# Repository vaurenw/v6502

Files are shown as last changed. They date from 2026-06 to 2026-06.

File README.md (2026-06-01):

A single-board computer built around a W65C02S 6502 CPU. It uses a Lattice ICE40HX4K FPGA as a custom chipset. The FPGA handles video, audio, keyboard, storage, and address decoding.

---

## Hardware

| Part | What it does |
|---|---|
| W65C02S | Main CPU, socketed |
| ICE40HX4K | FPGA chipset for video, audio, IO |
| 62256 SRAM | 32K RAM, socketed |
| AT28C256 EEPROM | 32K ROM, socketed |
| SN74LVC8T245 × 2 | 5V ↔ 3.3V level shifters for the data bus |
| FT230XS | USB-to-UART bridge for debug |
| MicroSD slot | SPI storage via FPGA |
| VGA connector | 640×480 @ 60Hz, resistor ladder DAC |
| PS/2 connector | Keyboard input, decoded in FPGA |

---

## Memory map

```
0x0000 – 0x7FFF   RAM
0x8000 – 0x8FFF   FPGA registers / VRAM window
0x9000 – 0xBFFF   Expansion
0xC000 – 0xFFFF   ROM
```

---

## Schematic sheets

```
V-6502.kicad_sch       root
├── Power.kicad_sch    USB-C, TVS, LDOs, decoupling
├── CPU.kicad_sch      W65C02S, clock, reset
├── Memory.kicad_sch   SRAM, EEPROM
├── LevelShift.kicad_sch   SN74LVC8T245 data bus bridges
├── FPGA.kicad_sch     ICE40HX4K, config flash, oscillator
├── VGA.kicad_sch      DE-15, RGB resistor ladder
├── PS2.kicad_sch      Mini-DIN-6, ESD, pull-ups
├── SD.kicad_sch       MicroSD slot, SPI
├── Audio.kicad_sch    Buzzer, 3.5mm jack
└── Debug.kicad_sch    FT230XS, UART header, test points
```

---

## Status

**Schematic done.** ERC passes clean.

**PCB layout in progress.** The power section is partially routed.

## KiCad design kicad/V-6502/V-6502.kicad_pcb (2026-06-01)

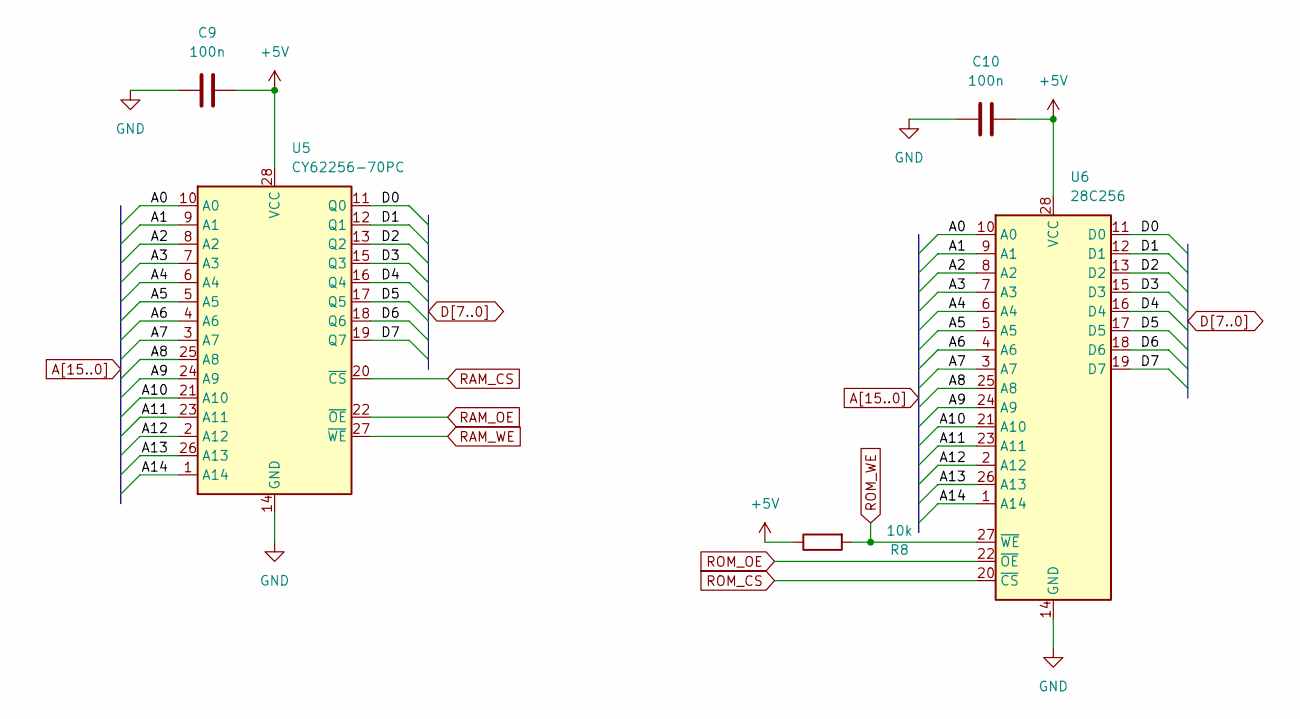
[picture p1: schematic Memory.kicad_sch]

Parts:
C9, C10: 100n; C_0805_2012Metric
R8: 10k; R_0402_1005Metric
U5: CY62256-70PC; DIP-28_W15.24mm_Socket
U6: 28C256; DIP-28_W15.24mm_Socket

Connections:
+5V: C9.2, C10.2, R8.1, U5.28 (VCC), U6.28 (VCC); also elsewhere on the board
A0: U5.10 (A0), U6.10 (A0); also elsewhere on the board
A1: U5.9 (A1), U6.9 (A1); also elsewhere on the board
A2: U5.8 (A2), U6.8 (A2); also elsewhere on the board
A3: U5.7 (A3), U6.7 (A3); also elsewhere on the board
A4: U5.6 (A4), U6.6 (A4); also elsewhere on the board
A5: U5.5 (A5), U6.5 (A5); also elsewhere on the board
A6: U5.4 (A6), U6.4 (A6); also elsewhere on the board
A7: U5.3 (A7), U6.3 (A7); also elsewhere on the board
A8: U5.25 (A8), U6.25 (A8); also elsewhere on the board
A9: U5.24 (A9), U6.24 (A9); also elsewhere on the board
A10: U5.21 (A10), U6.21 (A10); also elsewhere on the board
A11: U5.23 (A11), U6.23 (A11); also elsewhere on the board
A12: U5.2 (A12), U6.2 (A12); also elsewhere on the board
A13: U5.26 (A13), U6.26 (A13); also elsewhere on the board
A14: U5.1 (A14), U6.1 (A14); also elsewhere on the board
D0: U5.11 (Q0), U6.11 (D0); also elsewhere on the board
D1: U5.12 (Q1), U6.12 (D1); also elsewhere on the board
D2: U5.13 (Q2), U6.13 (D2); also elsewhere on the board
D3: U5.15 (Q3), U6.15 (D3); also elsewhere on the board
D4: U5.16 (Q4), U6.16 (D4); also elsewhere on the board
D5: U5.17 (Q5), U6.17 (D5); also elsewhere on the board
D6: U5.18 (Q6), U6.18 (D6); also elsewhere on the board
D7: U5.19 (Q7), U6.19 (D7); also elsewhere on the board
GND: C9.1, C10.1, U5.14 (GND), U6.14 (GND); also elsewhere on the board
RAM_CS: U5.20 (~CS); also elsewhere on the board
RAM_OE: U5.22 (~OE); also elsewhere on the board
RAM_WE: U5.27 (~WE); also elsewhere on the board
ROM_CS: U6.20 (~CS); also elsewhere on the board
ROM_OE: U6.22 (~OE); also elsewhere on the board
ROM_WE: R8.2, U6.27 (~WE); also elsewhere on the board

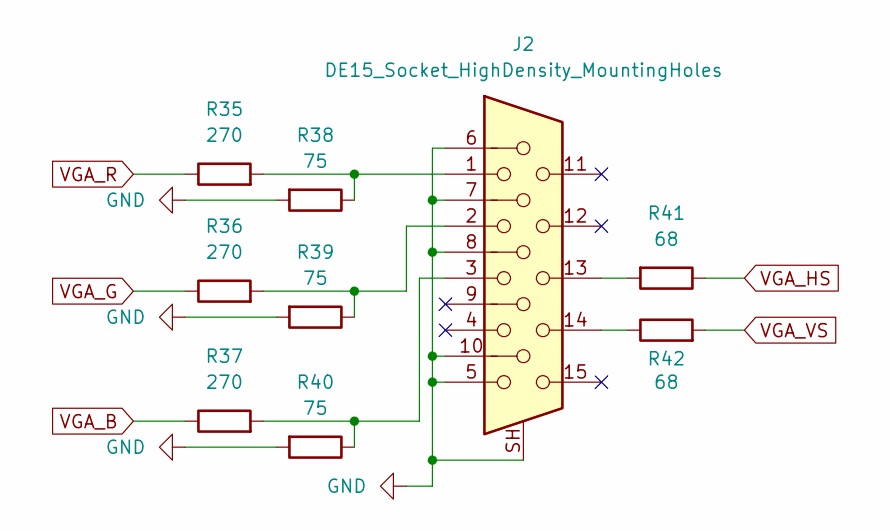
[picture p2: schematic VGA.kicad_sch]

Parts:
J2: DE15_Socket_HighDensity_MountingHoles; DSUB-15-HD_Socket_Vertical_P2.29x1.98mm_MountingHoles
R35, R36, R37: 270; R_0402_1005Metric
R38, R39, R40: 75; R_0402_1005Metric
R41, R42: 68; R_0402_1005Metric

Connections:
GND: J2.5, J2.6, J2.7, J2.8, J2.10, J2.SH, R38.2, R39.2, R40.2; also elsewhere on the board
unnamed: J2.1, R35.2, R38.1
unnamed: J2.2, R36.2, R39.1
unnamed: J2.3, R37.2, R40.1
unnamed: J2.13, R41.2
unnamed: J2.14, R42.1
VGA_B: R37.1; also elsewhere on the board
VGA_G: R36.1; also elsewhere on the board
VGA_HS: R41.1; also elsewhere on the board
VGA_R: R35.1; also elsewhere on the board
VGA_VS: R42.2; also elsewhere on the board

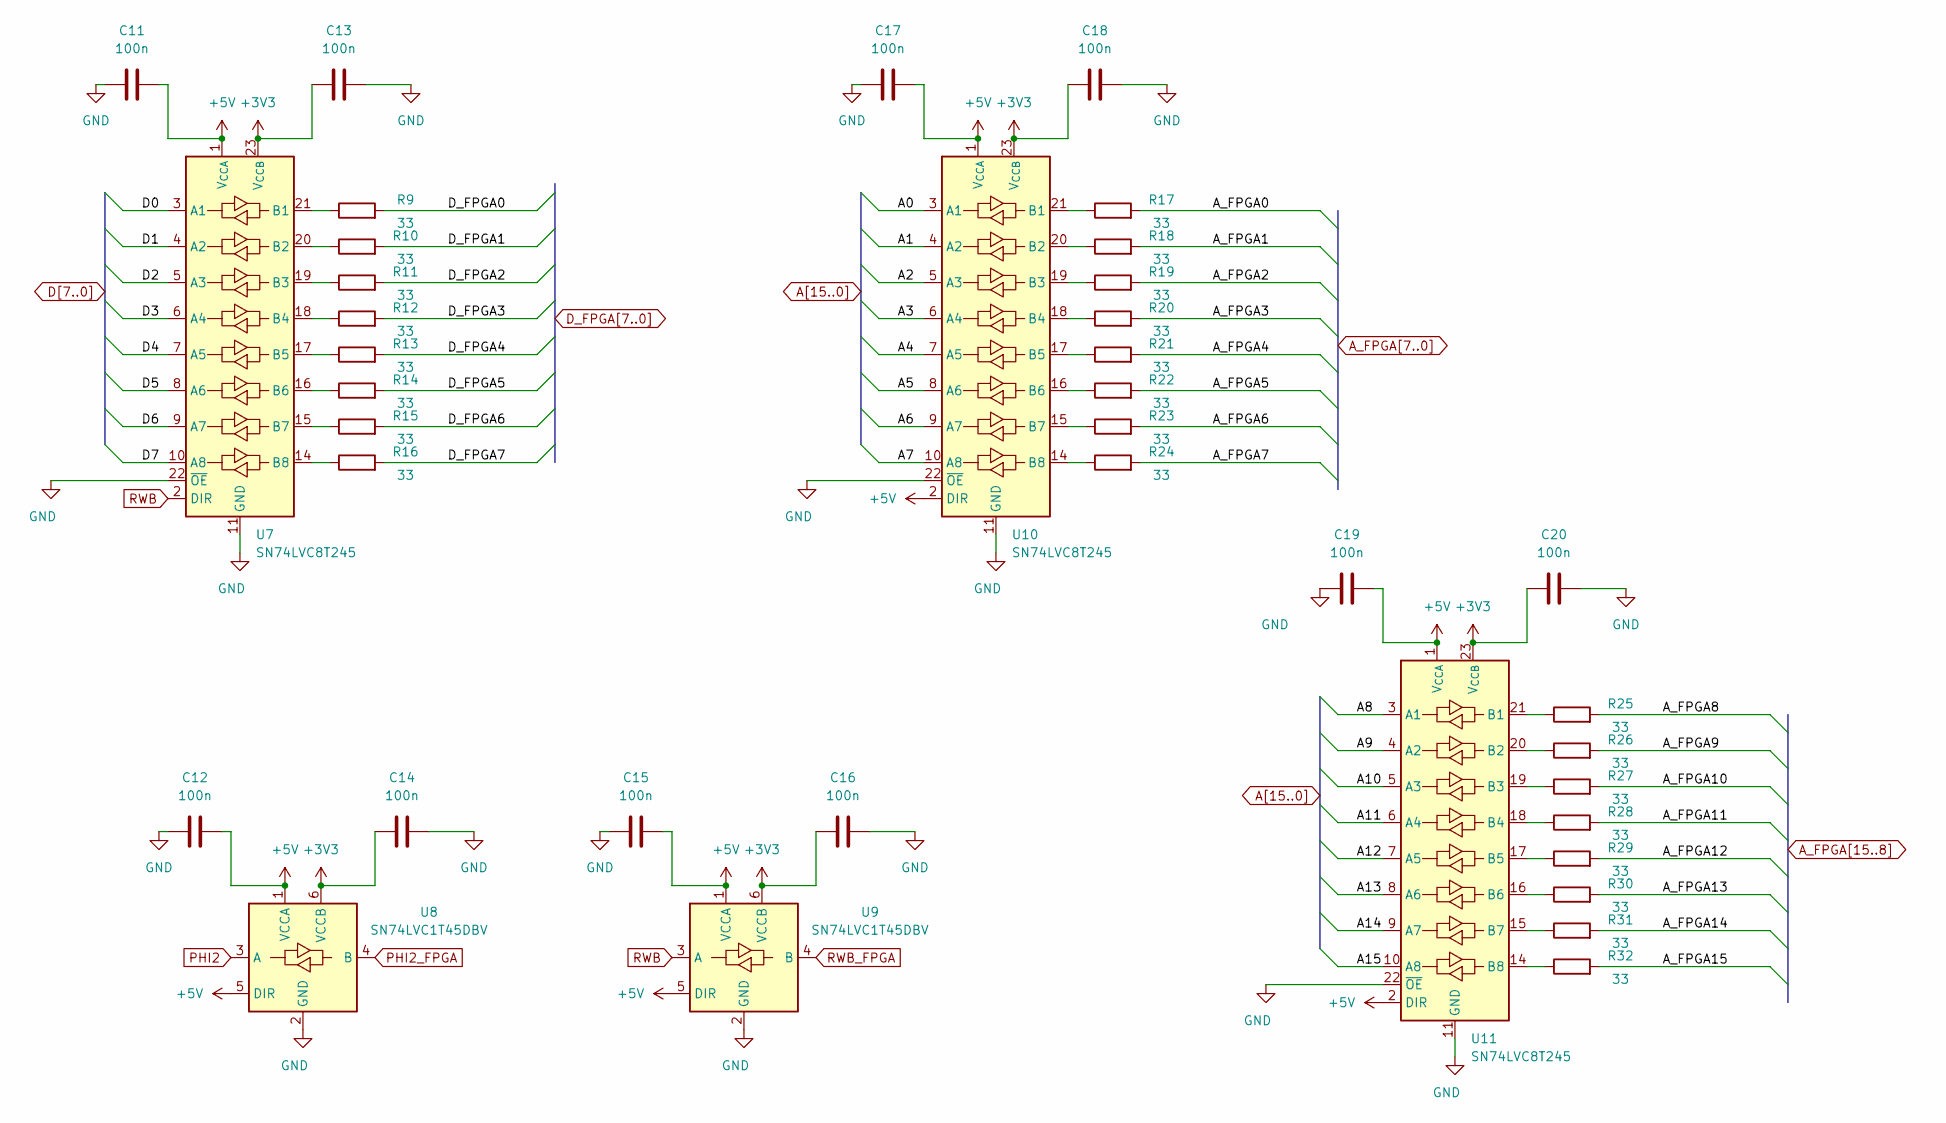
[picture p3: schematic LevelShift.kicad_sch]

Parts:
C11, C12, C13, C14, C15, C16, C17, C18, C19, C20: 100n; C_0805_2012Metric
R9, R10, R11, R12, R13, R14, R15, R16, R17, R18, R19, R20, R21, R22, R23, R24, R25, R26, R27, R28, R29, R30, R31, R32: 33; R_0402_1005Metric
U7, U10, U11: SN74LVC8T245; TSSOP-24_4.4x7.8mm_P0.65mm
U8, U9: SN74LVC1T45DBV; SOT-23-6

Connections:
+3V3: C13.2, C14.2, C16.2, C18.2, C20.2, U7.23 (V_{CCB}), U7.24 (V_{CCB}), U8.6 (VCCB), U9.6 (VCCB), U10.23 (V_{CCB}), U10.24 (V_{CCB}), U11.23 (V_{CCB}), U11.24 (V_{CCB}); also elsewhere on the board
+5V: C11.2, C12.2, C15.2, C17.2, C19.2, U7.1 (V_{CCA}), U8.1 (VCCA), U8.5 (DIR), U9.1 (VCCA), U9.5 (DIR), U10.1 (V_{CCA}), U10.2 (DIR), U11.1 (V_{CCA}), U11.2 (DIR); also elsewhere on the board
A0: U10.3 (A1); also elsewhere on the board
A1: U10.4 (A2); also elsewhere on the board
A2: U10.5 (A3); also elsewhere on the board
A3: U10.6 (A4); also elsewhere on the board
A4: U10.7 (A5); also elsewhere on the board
A5: U10.8 (A6); also elsewhere on the board
A6: U10.9 (A7); also elsewhere on the board
A7: U10.10 (A8); also elsewhere on the board
A8: U11.3 (A1); also elsewhere on the board
A9: U11.4 (A2); also elsewhere on the board
A10: U11.5 (A3); also elsewhere on the board
A11: U11.6 (A4); also elsewhere on the board
A12: U11.7 (A5); also elsewhere on the board
A13: U11.8 (A6); also elsewhere on the board
A14: U11.9 (A7); also elsewhere on the board
A15: U11.10 (A8); also elsewhere on the board
A_FPGA0: R17.2; also elsewhere on the board
A_FPGA1: R18.2; also elsewhere on the board
A_FPGA2: R19.2; also elsewhere on the board
A_FPGA3: R20.2; also elsewhere on the board
A_FPGA4: R21.2; also elsewhere on the board
A_FPGA5: R22.2; also elsewhere on the board
A_FPGA6: R23.2; also elsewhere on the board
A_FPGA7: R24.2; also elsewhere on the board
A_FPGA8: R25.2; also elsewhere on the board
A_FPGA9: R26.2; also elsewhere on the board
A_FPGA10: R27.2; also elsewhere on the board
A_FPGA11: R28.2; also elsewhere on the board
A_FPGA12: R29.2; also elsewhere on the board
A_FPGA13: R30.2; also elsewhere on the board
A_FPGA14: R31.2; also elsewhere on the board
A_FPGA15: R32.2; also elsewhere on the board
D0: U7.3 (A1); also elsewhere on the board
D1: U7.4 (A2); also elsewhere on the board
D2: U7.5 (A3); also elsewhere on the board
D3: U7.6 (A4); also elsewhere on the board
D4: U7.7 (A5); also elsewhere on the board
D5: U7.8 (A6); also elsewhere on the board
D6: U7.9 (A7); also elsewhere on the board
D7: U7.10 (A8); also elsewhere on the board
D_FPGA0: R9.2; also elsewhere on the board
D_FPGA1: R10.2; also elsewhere on the board
D_FPGA2: R11.2; also elsewhere on the board
D_FPGA3: R12.2; also elsewhere on the board
D_FPGA4: R13.2; also elsewhere on the board
D_FPGA5: R14.2; also elsewhere on the board
D_FPGA6: R15.2; also elsewhere on the board
D_FPGA7: R16.2; also elsewhere on the board
GND: C11.1, C12.1, C13.1, C14.1, C15.1, C16.1, C17.1, C18.1, C19.1, C20.1, U7.11 (GND), U7.12 (GND), U7.13 (GND), U7.22 (~OE), U8.2 (GND), U9.2 (GND), U10.11 (GND), U10.12 (GND), U10.13 (GND), U10.22 (~OE), U11.11 (GND), U11.12 (GND), U11.13 (GND), U11.22 (~OE); also elsewhere on the board
unnamed: R9.1, U7.21 (B1)
unnamed: R10.1, U7.20 (B2)
unnamed: R11.1, U7.19 (B3)
unnamed: R12.1, U7.18 (B4)
unnamed: R13.1, U7.17 (B5)
unnamed: R14.1, U7.16 (B6)
unnamed: R15.1, U7.15 (B7)
unnamed: R16.1, U7.14 (B8)
unnamed: R17.1, U10.21 (B1)
unnamed: R18.1, U10.20 (B2)
unnamed: R19.1, U10.19 (B3)
unnamed: R20.1, U10.18 (B4)
unnamed: R21.1, U10.17 (B5)
unnamed: R22.1, U10.16 (B6)
unnamed: R23.1, U10.15 (B7)
unnamed: R24.1, U10.14 (B8)
unnamed: R25.1, U11.21 (B1)
unnamed: R26.1, U11.20 (B2)
unnamed: R27.1, U11.19 (B3)
unnamed: R28.1, U11.18 (B4)
unnamed: R29.1, U11.17 (B5)
unnamed: R30.1, U11.16 (B6)
unnamed: R31.1, U11.15 (B7)
unnamed: R32.1, U11.14 (B8)
PHI2: U8.3 (A); also elsewhere on the board
PHI2_FPGA: U8.4 (B); also elsewhere on the board
RWB: U7.2 (DIR), U9.3 (A); also elsewhere on the board
RWB_FPGA: U9.4 (B); also elsewhere on the board

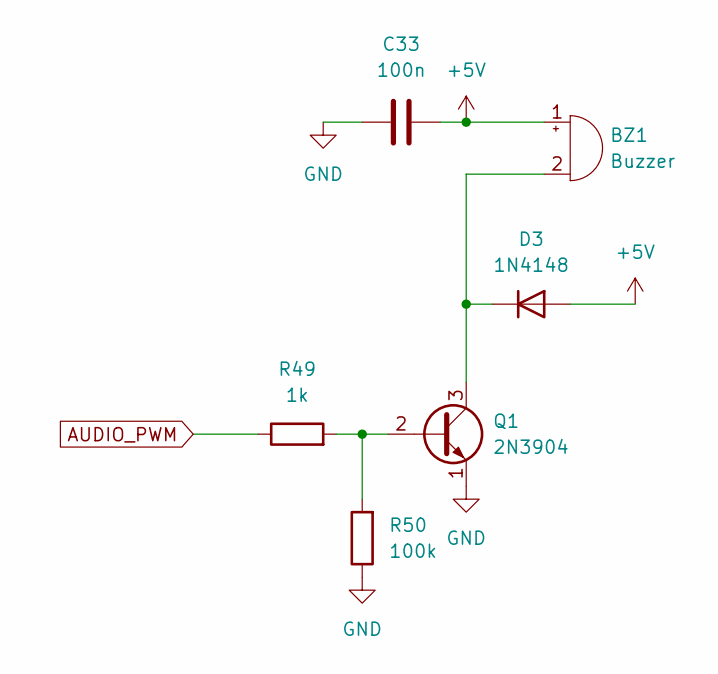
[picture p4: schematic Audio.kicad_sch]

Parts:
BZ1: Buzzer; Buzzer_15x7.5RM7.6
C33: 100n; C_0805_2012Metric
D3: 1N4148; D_DO-35_SOD27_P7.62mm_Horizontal
Q1: 2N3904; TO-92_Inline
R49: 1k; R_0402_1005Metric
R50: 100k; R_0402_1005Metric

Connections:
+5V: BZ1.1 (+), C33.2, D3.2 (A); also elsewhere on the board
AUDIO_PWM: R49.1; also elsewhere on the board
GND: C33.1, Q1.1 (E), R50.1; also elsewhere on the board
unnamed: BZ1.2 (-), D3.1 (K), Q1.3 (C)
unnamed: Q1.2 (B), R49.2, R50.2

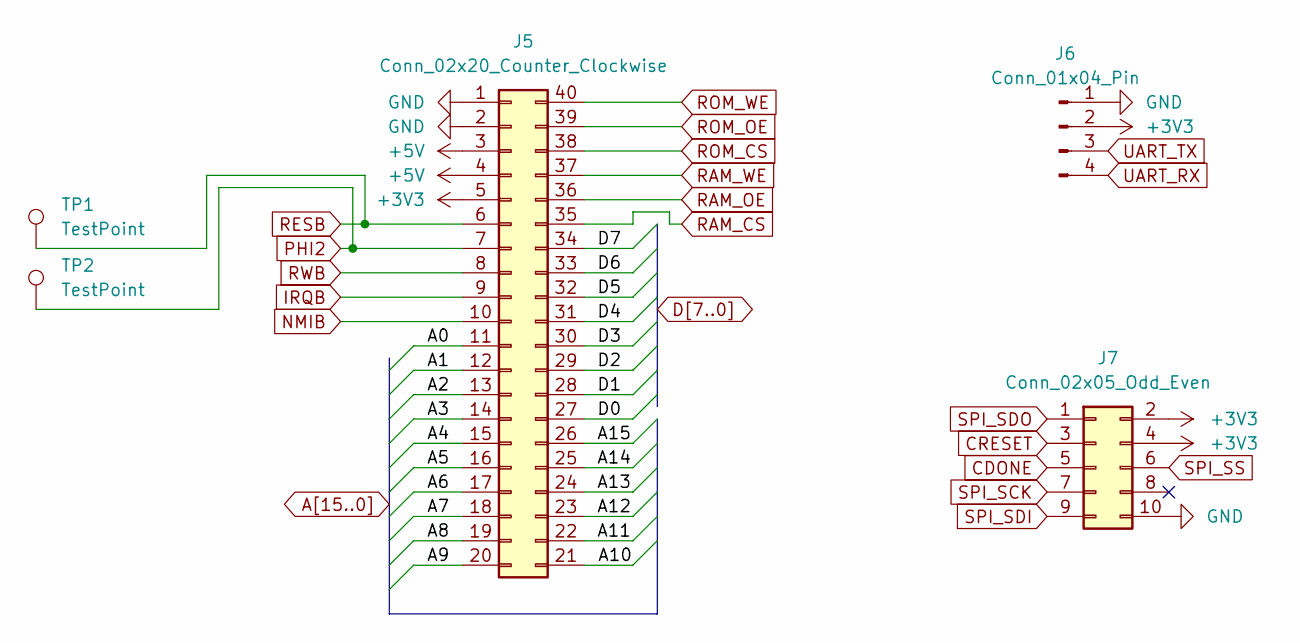
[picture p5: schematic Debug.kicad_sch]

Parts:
J5: Conn_02x20_Counter_Clockwise; PinSocket_2x20_P2.54mm_Vertical
J6: Conn_01x04_Pin; PinHeader_1x04_P2.54mm_Vertical
J7: Conn_02x05_Odd_Even; IDC-Header_2x05_P2.54mm_Vertical
TP1, TP2: TestPoint; TestPoint_Pad_D1.0mm

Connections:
+3V3: J5.5, J6.2, J7.2, J7.4; also elsewhere on the board
+5V: J5.3, J5.4; also elsewhere on the board
A0: J5.11; also elsewhere on the board
A1: J5.12; also elsewhere on the board
A2: J5.13; also elsewhere on the board
A3: J5.14; also elsewhere on the board
A4: J5.15; also elsewhere on the board
A5: J5.16; also elsewhere on the board
A6: J5.17; also elsewhere on the board
A7: J5.18; also elsewhere on the board
A8: J5.19; also elsewhere on the board
A9: J5.20; also elsewhere on the board
A10: J5.21; also elsewhere on the board
A11: J5.22; also elsewhere on the board
A12: J5.23; also elsewhere on the board
A13: J5.24; also elsewhere on the board
A14: J5.25; also elsewhere on the board
A15: J5.26; also elsewhere on the board
CDONE: J7.5; also elsewhere on the board
CRESET: J7.3; also elsewhere on the board
D0: J5.27; also elsewhere on the board
D1: J5.28; also elsewhere on the board
D2: J5.29; also elsewhere on the board
D3: J5.30; also elsewhere on the board
D4: J5.31; also elsewhere on the board
D5: J5.32; also elsewhere on the board
D6: J5.33; also elsewhere on the board
D7: J5.34; also elsewhere on the board
GND: J5.1, J5.2, J6.1, J7.10; also elsewhere on the board
IRQB: J5.9; also elsewhere on the board
NMIB: J5.10; also elsewhere on the board
PHI2: J5.7, TP2.1 (1_1); also elsewhere on the board
RAM_CS: J5.35; also elsewhere on the board
RAM_OE: J5.36; also elsewhere on the board
RAM_WE: J5.37; also elsewhere on the board
RESB: J5.6, TP1.1 (1_1); also elsewhere on the board
ROM_CS: J5.38; also elsewhere on the board
ROM_OE: J5.39; also elsewhere on the board
ROM_WE: J5.40; also elsewhere on the board
RWB: J5.8; also elsewhere on the board
SPI_SCK: J7.7; also elsewhere on the board
SPI_SDI: J7.9; also elsewhere on the board
SPI_SDO: J7.1; also elsewhere on the board
SPI_SS: J7.6; also elsewhere on the board
UART_RX: J6.4; also elsewhere on the board
UART_TX: J6.3; also elsewhere on the board

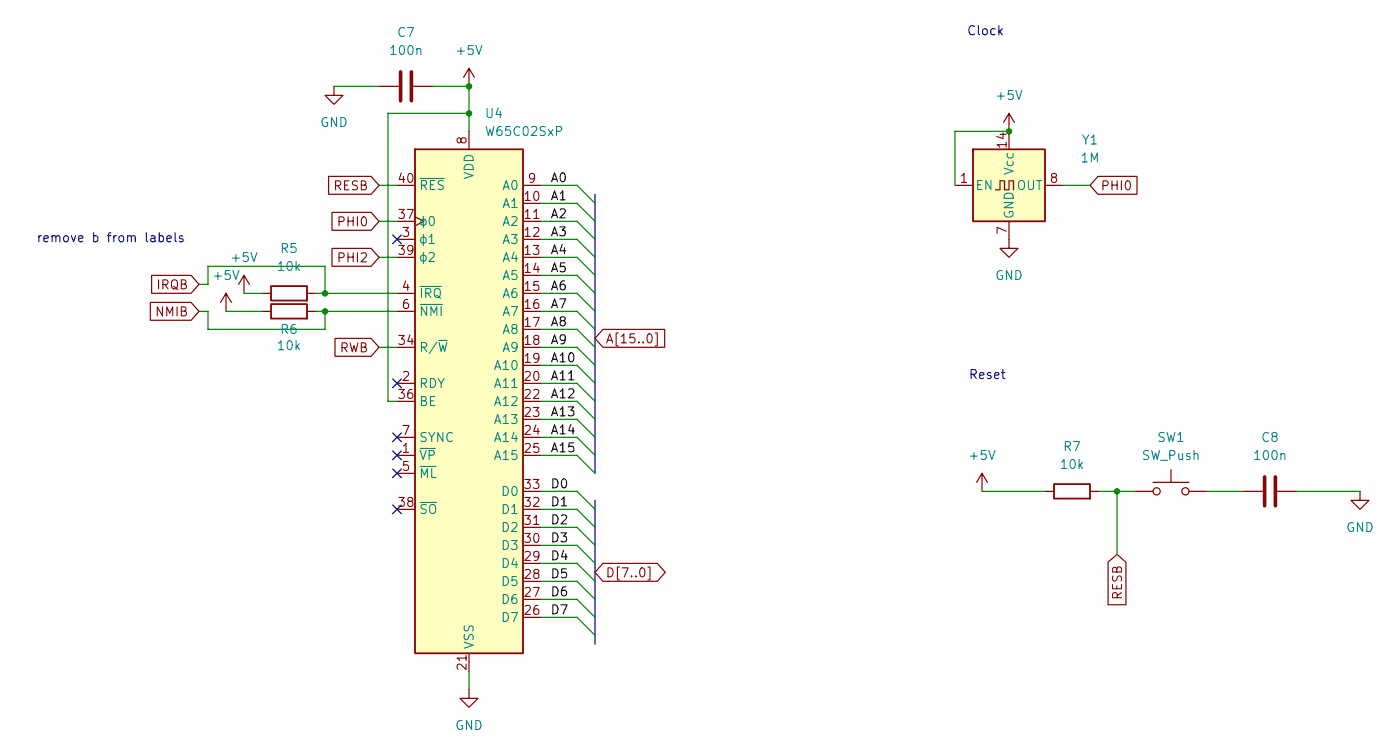
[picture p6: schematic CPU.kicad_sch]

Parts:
C7, C8: 100n; C_0805_2012Metric
R5, R6, R7: 10k; R_0402_1005Metric
SW1: SW_Push; SW_PUSH_6mm
U4: W65C02SxP; DIP-40_W15.24mm_Socket
Y1: 1M; Oscillator_DIP-14

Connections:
+5V: C7.2, R5.1, R6.1, R7.1, U4.8 (VDD), U4.36 (BE), Y1.1 (EN), Y1.14 (Vcc); also elsewhere on the board
A0: U4.9 (A0); also elsewhere on the board
A1: U4.10 (A1); also elsewhere on the board
A2: U4.11 (A2); also elsewhere on the board
A3: U4.12 (A3); also elsewhere on the board
A4: U4.13 (A4); also elsewhere on the board
A5: U4.14 (A5); also elsewhere on the board
A6: U4.15 (A6); also elsewhere on the board
A7: U4.16 (A7); also elsewhere on the board
A8: U4.17 (A8); also elsewhere on the board
A9: U4.18 (A9); also elsewhere on the board
A10: U4.19 (A10); also elsewhere on the board
A11: U4.20 (A11); also elsewhere on the board
A12: U4.22 (A12); also elsewhere on the board
A13: U4.23 (A13); also elsewhere on the board
A14: U4.24 (A14); also elsewhere on the board
A15: U4.25 (A15); also elsewhere on the board
D0: U4.33 (D0); also elsewhere on the board
D1: U4.32 (D1); also elsewhere on the board
D2: U4.31 (D2); also elsewhere on the board
D3: U4.30 (D3); also elsewhere on the board
D4: U4.29 (D4); also elsewhere on the board
D5: U4.28 (D5); also elsewhere on the board
D6: U4.27 (D6); also elsewhere on the board
D7: U4.26 (D7); also elsewhere on the board
GND: C7.1, C8.2, U4.21 (VSS), Y1.7 (GND); also elsewhere on the board
IRQB: R5.2, U4.4 (~IRQ); also elsewhere on the board
NMIB: R6.2, U4.6 (~NMI); also elsewhere on the board
unnamed: C8.1, SW1.2
PHI0: U4.37 (ϕ0), Y1.8 (OUT)
PHI2: U4.39 (ϕ2); also elsewhere on the board
RESB: R7.2, SW1.1, U4.40 (~RES); also elsewhere on the board
RWB: U4.34 (R/~W); also elsewhere on the board

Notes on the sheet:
Reset
remove b from labels
Clock

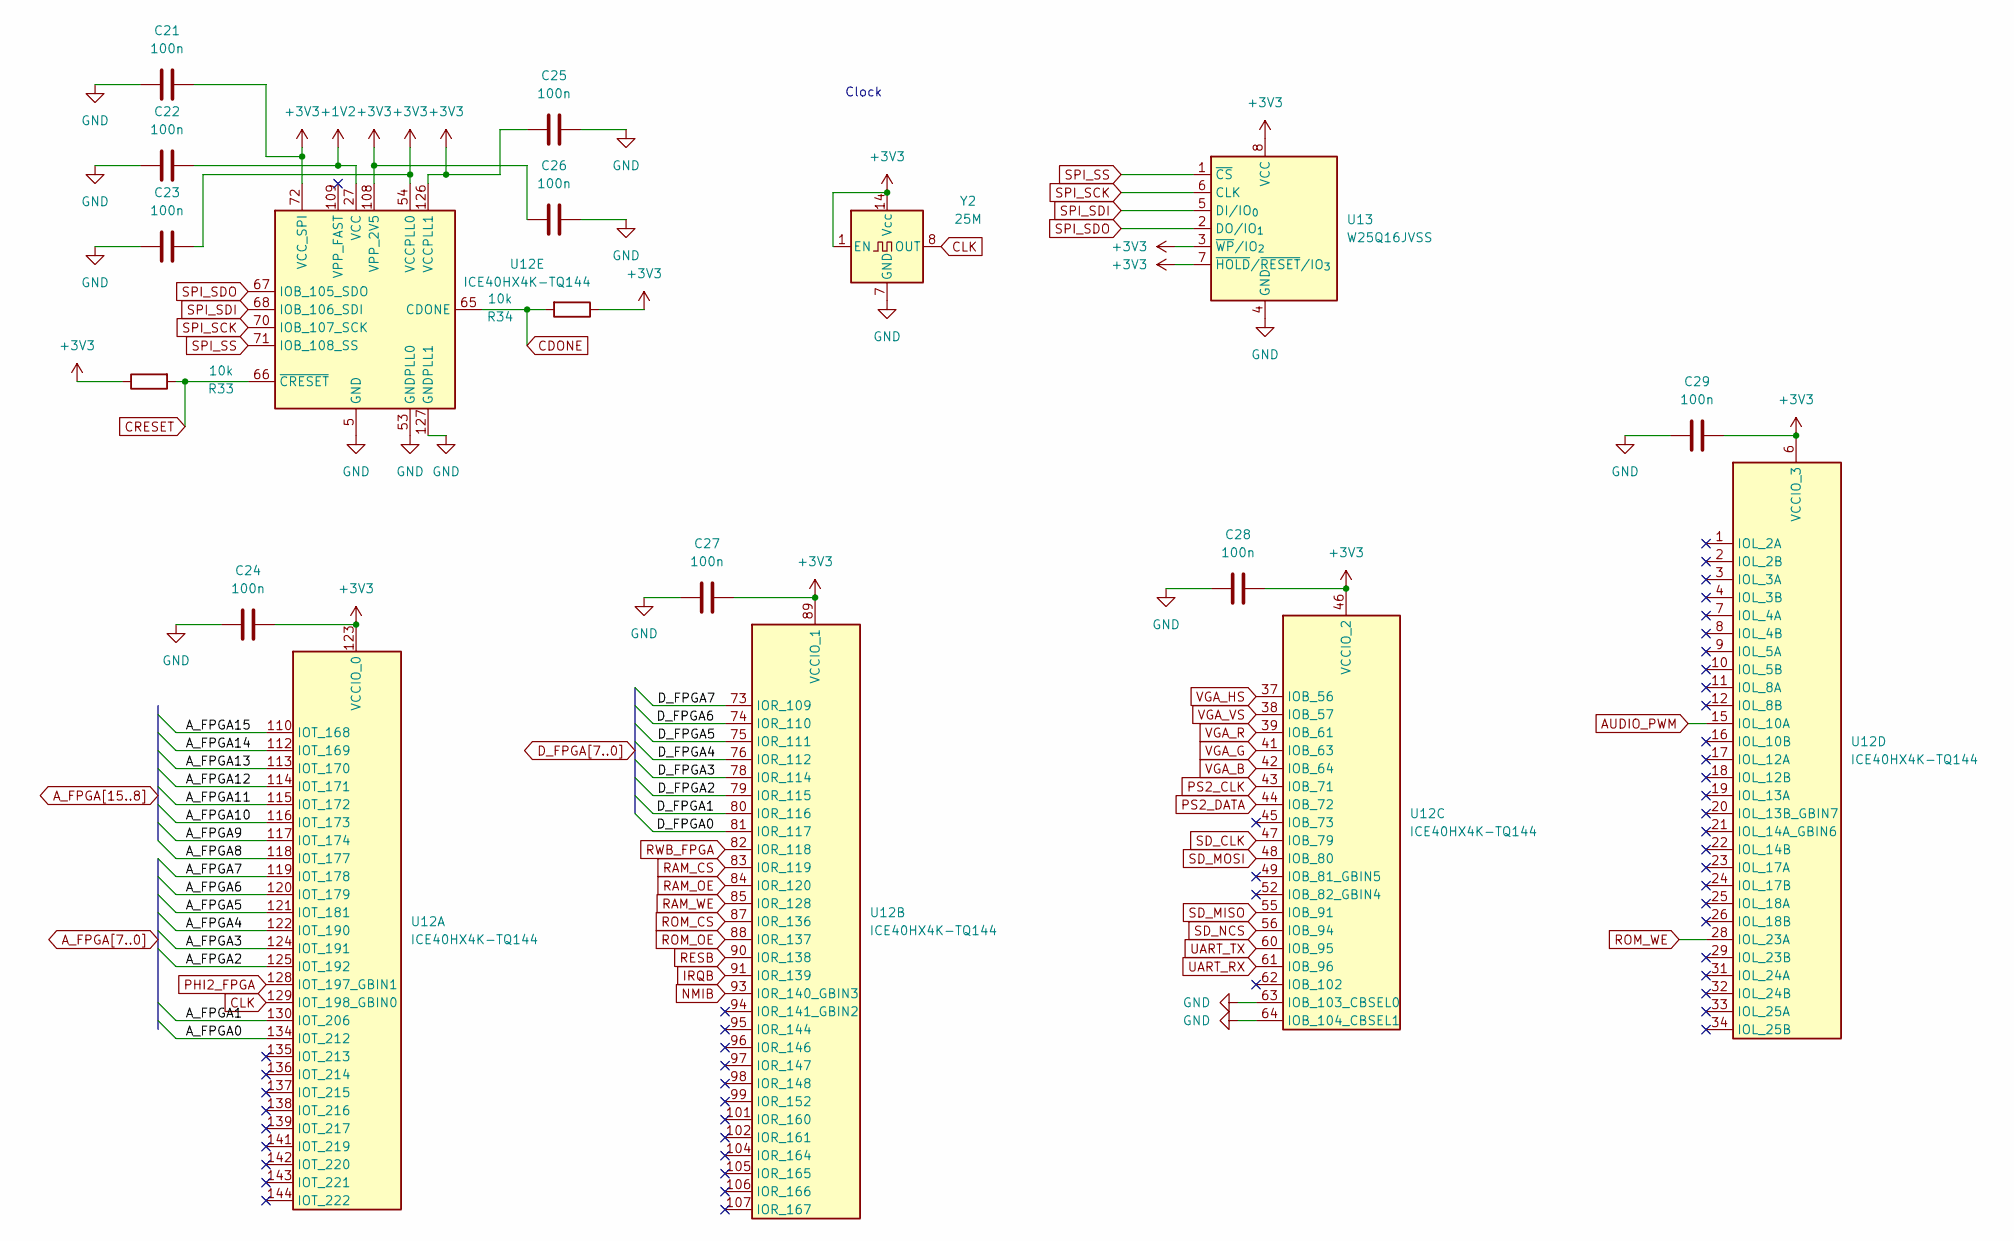
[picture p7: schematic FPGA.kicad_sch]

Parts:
C21, C22, C23, C24, C25, C26, C27, C28, C29: 100n; C_0805_2012Metric
R33, R34: 10k; R_0402_1005Metric
U12: ICE40HX4K-TQ144; TQFP-144_20x20mm_P0.5mm
U13: W25Q16JVSS; SOIC-8_5.3x5.3mm_P1.27mm
Y2: 25M; Oscillator_DIP-14

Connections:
+1V2: C22.2, U12.27 (VCC), U12.40 (VCC), U12.92 (VCC), U12.111 (VCC); also elsewhere on the board
+3V3: C21.2, C23.2, C24.2, C25.2, C26.2, C27.2, C28.2, C29.2, R33.1, R34.1, U12.6 (VCCIO_3), U12.30 (VCCIO_3), U12.46 (VCCIO_2), U12.54 (VCCPLL0), U12.57 (VCCIO_2), U12.72 (VCC_SPI), U12.89 (VCCIO_1), U12.100 (VCCIO_1), U12.108 (VPP_2V5), U12.123 (VCCIO_0), U12.126 (VCCPLL1), U12.131 (VCCIO_0), U13.3 (~WP/IO_{2}), U13.7 (~HOLD/~RESET/IO_{3}), U13.8 (VCC), Y2.1 (EN), Y2.14 (Vcc); also elsewhere on the board
AUDIO_PWM: U12.15 (IOL_10A); also elsewhere on the board
A_FPGA0: U12.134 (IOT_212); also elsewhere on the board
A_FPGA1: U12.130 (IOT_206); also elsewhere on the board
A_FPGA2: U12.125 (IOT_192); also elsewhere on the board
A_FPGA3: U12.124 (IOT_191); also elsewhere on the board
A_FPGA4: U12.122 (IOT_190); also elsewhere on the board
A_FPGA5: U12.121 (IOT_181); also elsewhere on the board
A_FPGA6: U12.120 (IOT_179); also elsewhere on the board
A_FPGA7: U12.119 (IOT_178); also elsewhere on the board
A_FPGA8: U12.118 (IOT_177); also elsewhere on the board
A_FPGA9: U12.117 (IOT_174); also elsewhere on the board
A_FPGA10: U12.116 (IOT_173); also elsewhere on the board
A_FPGA11: U12.115 (IOT_172); also elsewhere on the board
A_FPGA12: U12.114 (IOT_171); also elsewhere on the board
A_FPGA13: U12.113 (IOT_170); also elsewhere on the board
A_FPGA14: U12.112 (IOT_169); also elsewhere on the board
A_FPGA15: U12.110 (IOT_168); also elsewhere on the board
CDONE: R34.2, U12.65 (CDONE); also elsewhere on the board
CLK: U12.129 (IOT_198_GBIN0), Y2.8 (OUT)
CRESET: R33.2, U12.66 (~CRESET); also elsewhere on the board
D_FPGA0: U12.81 (IOR_117); also elsewhere on the board
D_FPGA1: U12.80 (IOR_116); also elsewhere on the board
D_FPGA2: U12.79 (IOR_115); also elsewhere on the board
D_FPGA3: U12.78 (IOR_114); also elsewhere on the board
D_FPGA4: U12.76 (IOR_112); also elsewhere on the board
D_FPGA5: U12.75 (IOR_111); also elsewhere on the board
D_FPGA6: U12.74 (IOR_110); also elsewhere on the board
D_FPGA7: U12.73 (IOR_109); also elsewhere on the board
GND: C21.1, C22.1, C23.1, C24.1, C25.1, C26.1, C27.1, C28.1, C29.1, U12.5 (GND), U12.13 (GND), U12.14 (GND), U12.53 (GNDPLL0), U12.59 (GND), U12.63 (IOB_103_CBSEL0), U12.64 (IOB_104_CBSEL1), U12.69 (GND), U12.86 (GND), U12.103 (GND), U12.127 (GNDPLL1), U12.132 (GND), U12.140 (GND), U13.4 (GND), Y2.7 (GND); also elsewhere on the board
IRQB: U12.91 (IOR_139); also elsewhere on the board
NMIB: U12.93 (IOR_140_GBIN3); also elsewhere on the board
PHI2_FPGA: U12.128 (IOT_197_GBIN1); also elsewhere on the board
PS2_CLK: U12.43 (IOB_71); also elsewhere on the board
PS2_DATA: U12.44 (IOB_72); also elsewhere on the board
RAM_CS: U12.83 (IOR_119); also elsewhere on the board
RAM_OE: U12.84 (IOR_120); also elsewhere on the board
RAM_WE: U12.85 (IOR_128); also elsewhere on the board
RESB: U12.90 (IOR_138); also elsewhere on the board
ROM_CS: U12.87 (IOR_136); also elsewhere on the board
ROM_OE: U12.88 (IOR_137); also elsewhere on the board
ROM_WE: U12.28 (IOL_23A); also elsewhere on the board
RWB_FPGA: U12.82 (IOR_118); also elsewhere on the board
SD_CLK: U12.47 (IOB_79); also elsewhere on the board
SD_MISO: U12.55 (IOB_91); also elsewhere on the board
SD_MOSI: U12.48 (IOB_80); also elsewhere on the board
SD_NCS: U12.56 (IOB_94); also elsewhere on the board
SPI_SCK: U12.70 (IOB_107_SCK), U13.6 (CLK); also elsewhere on the board
SPI_SDI: U12.68 (IOB_106_SDI), U13.5 (DI/IO_{0}); also elsewhere on the board
SPI_SDO: U12.67 (IOB_105_SDO), U13.2 (DO/IO_{1}); also elsewhere on the board
SPI_SS: U12.71 (IOB_108_SS), U13.1 (~CS); also elsewhere on the board
UART_RX: U12.61 (IOB_96); also elsewhere on the board
UART_TX: U12.60 (IOB_95); also elsewhere on the board
VGA_B: U12.42 (IOB_64); also elsewhere on the board
VGA_G: U12.41 (IOB_63); also elsewhere on the board
VGA_HS: U12.37 (IOB_56); also elsewhere on the board
VGA_R: U12.39 (IOB_61); also elsewhere on the board
VGA_VS: U12.38 (IOB_57); also elsewhere on the board

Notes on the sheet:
Clock

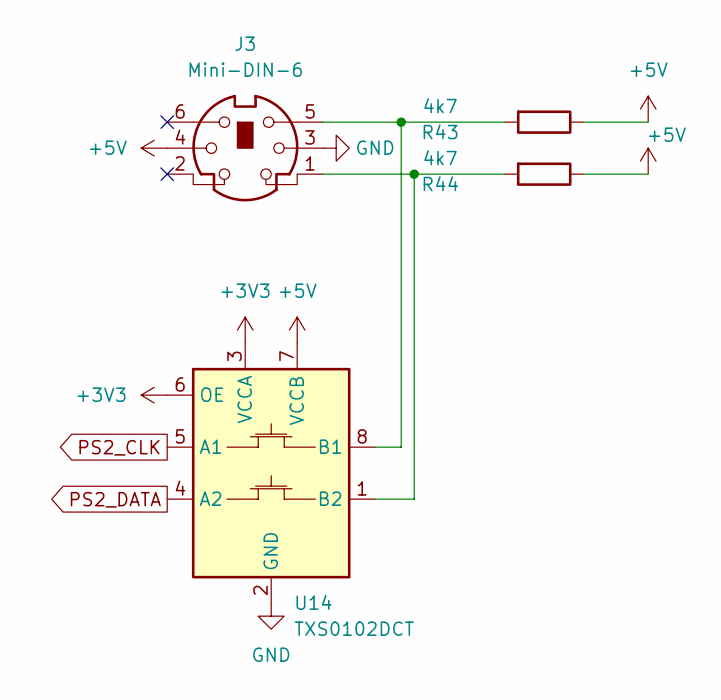
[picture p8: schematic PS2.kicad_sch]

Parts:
J3: Mini-DIN-6; Connector_Mini-DIN_Female_6Pin_2rows
R43, R44: 4k7; R_0402_1005Metric
U14: TXS0102DCT; SSOP-8_2.95x2.8mm_P0.65mm

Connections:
+3V3: U14.3 (VCCA), U14.6 (OE); also elsewhere on the board
+5V: J3.4, R43.1, R44.1, U14.7 (VCCB); also elsewhere on the board
GND: J3.3, U14.2 (GND); also elsewhere on the board
unnamed: J3.5, R43.2, U14.8 (B1)
unnamed: J3.1, R44.2, U14.1 (B2)
PS2_CLK: U14.5 (A1); also elsewhere on the board
PS2_DATA: U14.4 (A2); also elsewhere on the board

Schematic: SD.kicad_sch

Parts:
C30, C31, C32: 100n; C_0805_2012Metric
J4: Micro_SD_Card; microSD_HC_Molex_47219-2001
R45, R46, R47: 33; R_0402_1005Metric
R48: 10k; R_0402_1005Metric
U15: FT230XS; SSOP-16_3.9x4.9mm_P0.635mm

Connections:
+3V3: C30.2, C31.2, C32.2, J4.4 (VDD), R48.1, U15.3 (VCCIO), U15.12 (VCC); also elsewhere on the board
GND: C30.1, C31.1, C32.1, J4.6 (VSS), J4.SH (SHIELD), U15.5 (GND), U15.13 (GND); also elsewhere on the board
unnamed: J4.5 (CLK), R47.2
unnamed: J4.3 (CMD), R46.2
unnamed: J4.2 (DAT3/CD), R45.2
unnamed: R48.2, U15.11 (~RESET)
SD_CLK: R47.1; also elsewhere on the board
SD_MISO: J4.7 (DAT0); also elsewhere on the board
SD_MOSI: R46.1; also elsewhere on the board
SD_NCS: R45.1; also elsewhere on the board
UART_RX: U15.1 (TXD); also elsewhere on the board
UART_TX: U15.4 (RXD); also elsewhere on the board
USB_D+: U15.8 (USBDP); also elsewhere on the board
USB_D-: U15.9 (USBDM); also elsewhere on the board

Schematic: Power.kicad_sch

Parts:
C1, C2, C3, C4, C5, C6: 4u7; C_0805_2012Metric
D1: PESD5V0L1ULD; D_SOD-882D
D2: LED; LED_0805_2012Metric
J1: USB_C_Receptacle_USB2.0_16P; USB_C_Receptacle_GCT_USB4085
R1, R2: 5k1; R_0402_1005Metric
R3: 0R; R_0402_1005Metric
R4: 2k; R_0402_1005Metric
U1: USBLC6-2SC6; SOT-23-6
U2: AP2112K-3.3; SOT-23-5
U3: AP2112K-1.2; SOT-23-5

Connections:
+1V2: C6.1, U3.5 (VOUT); also elsewhere on the board
+3V3: C5.1, U2.5 (VOUT); also elsewhere on the board
+5V: C2.1, C3.1, C4.1, R3.2, R4.2, U2.1 (VIN), U2.3 (EN), U3.1 (VIN), U3.3 (EN); also elsewhere on the board
/Power/D+: J1.A6 (D+), J1.B6 (D+), U1.3 (I/O2)
/Power/D-: J1.A7 (D-), J1.B7 (D-), U1.1 (I/O1)
GND: C1.2, C2.2, C3.2, C4.2, C5.2, C6.2, D1.2 (A), D2.1 (K), J1.A1 (GND), J1.A12 (GND), J1.B1 (GND), J1.B12 (GND), J1.SH (SHIELD), R1.2, R2.2, U1.2 (GND), U2.2 (GND), U3.2 (GND); also elsewhere on the board
unnamed: D2.2 (A), R4.1
unnamed: J1.A5 (CC1), R2.1
unnamed: J1.B5 (CC2), R1.1
USB_D+: U1.4 (I/O2); also elsewhere on the board
USB_D-: U1.6 (I/O1); also elsewhere on the board
VBUS: C1.1, D1.1 (K), J1.A4 (VBUS), J1.A9 (VBUS), J1.B4 (VBUS), J1.B9 (VBUS), R3.1

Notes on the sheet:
3.3V LDO
1.2V LDO
Input Power and USBC
Power on LED

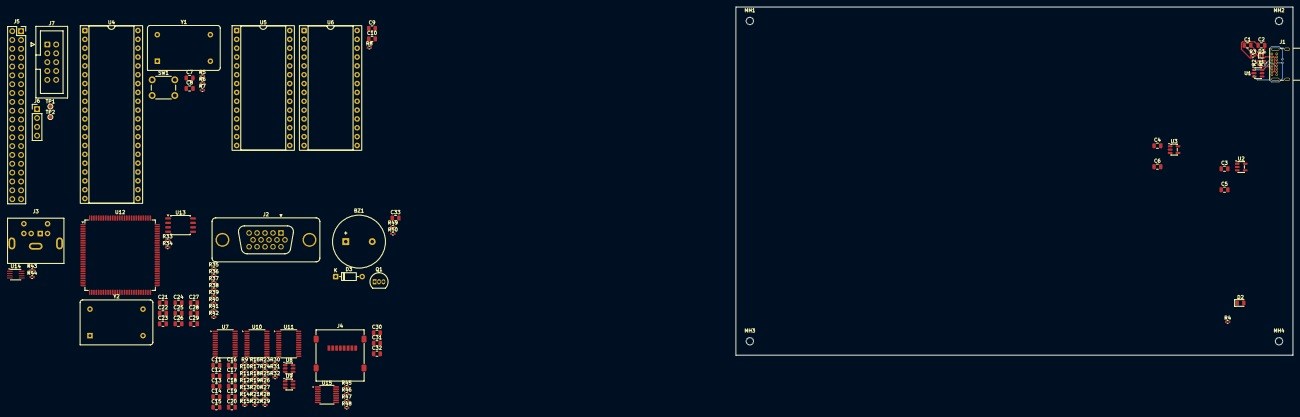
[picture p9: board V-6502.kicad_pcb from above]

Board: 2 copper layers, 160.0 x 100.0 mm, 119 parts (0 on the bottom side), 133 nets.

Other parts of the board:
MH1, MH2, MH3, MH4: MountingHole_2.1mm
